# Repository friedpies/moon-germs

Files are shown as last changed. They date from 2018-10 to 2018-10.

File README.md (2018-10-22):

## Moon Germs
#### A hand-held, battery powered digital synthesizer based on the Teensy 3.2 and Audio Shield by www.pjrc.com
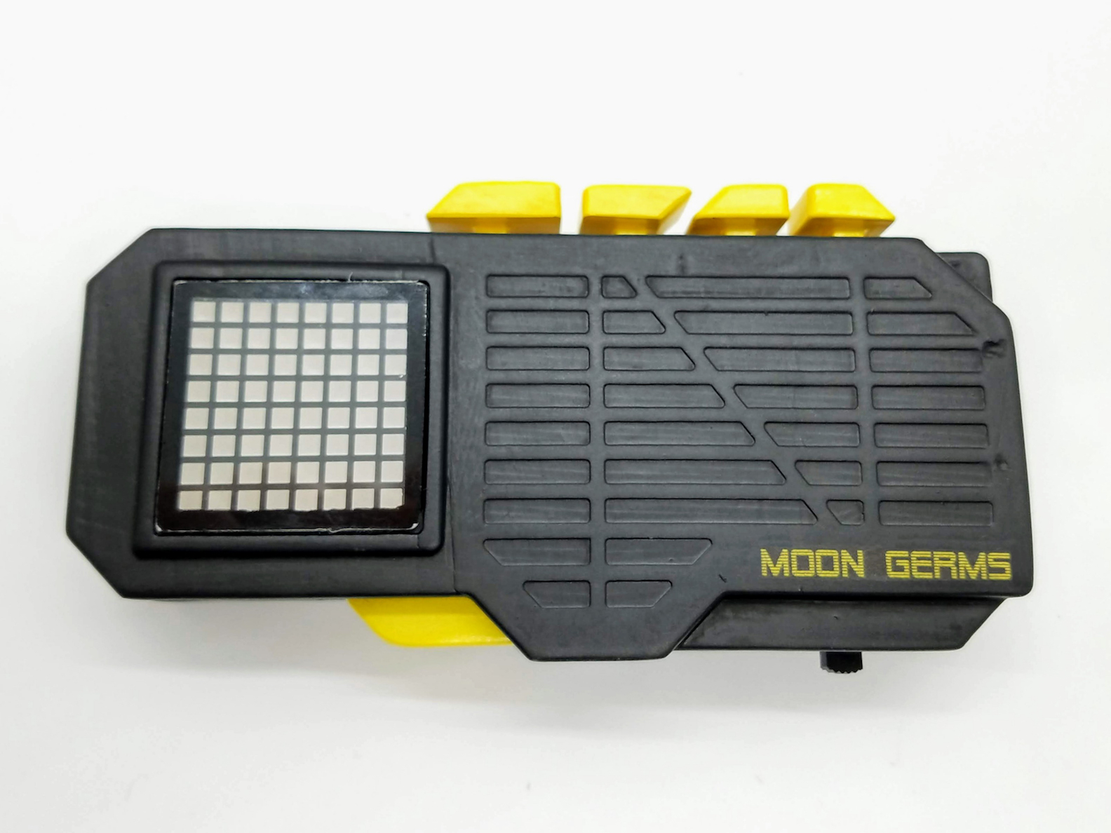
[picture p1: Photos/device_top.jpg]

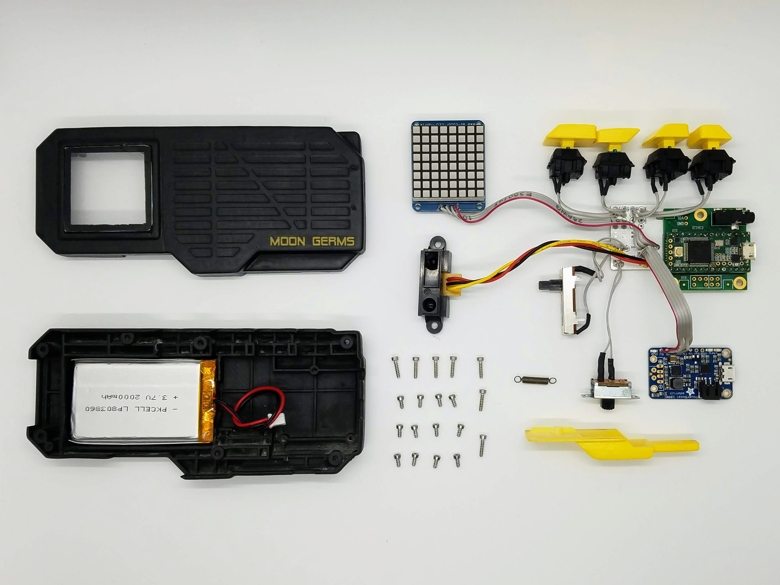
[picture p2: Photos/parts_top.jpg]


### Updates 10/21/18
*After making it into the semi-finals for the 2018 Hackaday challenge, I thought it would be fun to add some fun new features before submitting this project to the finals. In the past couple of days I've built a desktop app using Processing that connects to the device and allows you to update parameters in real time. I restructured the synth engine to include a LowPass filter and LFO. It was a pretty ambitious goal for me and I still have a lot of bugs to work out, but I have an MVP that works pretty well and looks pretty awesome too. See below for details about the app.*

### About the Device
A fun, pocket-sized synthesizer that uses an IR proximity sensor to modulate frequency. Using a combination of buttons and triggers, the device can produce several different waveforms and effects. An 8x8 LED matrix shows useful and colorful information while in use. Currently finishing up Rev 1.0

I wanted to explore digital synthesis using the Teensy Audio shield and experiment with a unique way of interacting with a synthesizer with minimal buttons/knobs, all while designing a device with an interesting and cyberpunk-y form factor. Although I'm a lifelong musician, I never really explored synthesis before and thought this would be a great way to dive in. This has been an awesome learning experience and has gotten me hooked! I'm excited to keep this up.

Traditional synthesizers can be intimidating to approach with all of their knobs, sliders and weird nomenclature, and difficult for a beginner to understand. This project aims to provide a fun and addicting way to mess around with a couple different waveforms and  explore creative and strange musical ideas. With only 4 buttons, and 2 analog inputs, interacting with the Moon Germs synthesizer and creating sound is really simple. Simply press down the "play" button and move your hand around relative to the IR sensor. Cycle through various waveforms with button 2, and switch octaves with buttons 3 & 4. For a "fatter" sound, apply force to the trigger to detune oscillator 2. The 8x8 display shows what type of waveform you're hearing, and dynamically speeds up or slows down with pitch.

When you're ready to take a deeper dive into the behind-the-scenes of synthesis, connect the device to the desktop app to adjust and tweak various parameters in a non-intimidating environment. Once connected, the app auto-loads the device's stored parameters according to their bank number. In addition to waveform selection, the adjustable parameters include oscillator volumes, detune amount, filter On/Off, cutoff, resonance, LFO on/off, rate, and amount. Additionally there is a trigger assignment option which allows the trigger to dynamic adjust parameters in real-time outside of the app. Currently, parameter adjustments will be saved on the device after disconnect, but will reset after a power cycle.

The entire design was made using open/free software and can be rebuilt with accessible tools and open electronics modules (see BOM).

--------
### Usage
The Moon Germs' synthesis engine is shown in the photo below. Pressing down button 1 activates the oscillators while their frequency is determined by the IR sensor. Button 2 cycles through 4 waveforms (saw, square, reverse saw, and triangle). Buttons 3 & 4 shift octaves up & down respectively. The spring loaded trigger applies a detune to oscillator 2. In standalone mode (not connected to the app), the filter and LFO are turned OFF for simplicity.
Device Demo
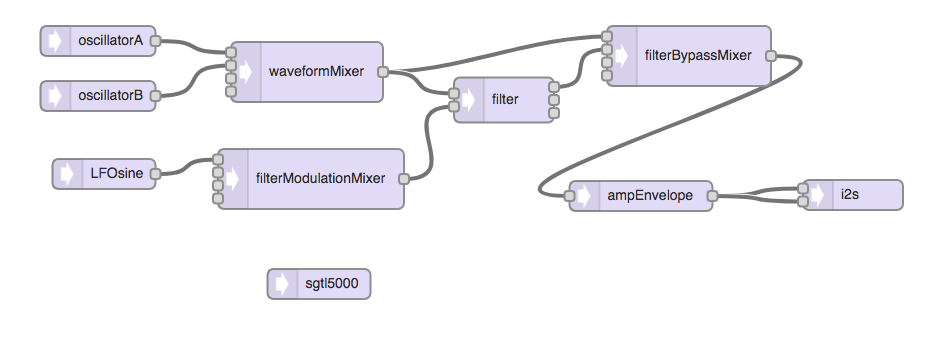
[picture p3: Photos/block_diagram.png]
Synth


### Desktop App
 Connecting the device to the desktop app allows the user to adjust various parameters to explore sound design. Once connected, the app auto-loads the device's stored parameters according to their bank number. In addition to waveform selection, the adjustable parameters include oscillator volumes, detune amount, filter On/Off, cutoff, resonance, LFO on/off, rate, and amount. Additionally there is a trigger assignment option which allows the trigger to dynamic adjust parameters in real-time outside of the app. Currently, parameter adjustments will be saved on the device after disconnect, but will reset after a power cycle.

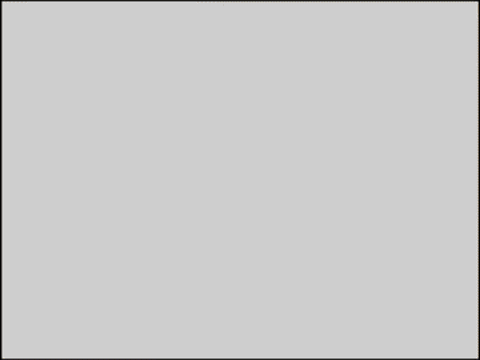
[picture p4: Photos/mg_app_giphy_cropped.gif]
App Demo


Desktop App Detail Information can be found [here](https://github.com/friedpies/moon-germs/tree/master/Desktop%20App)

--------
### Video Demos
[Submission Video](https://youtu.be/npFgwcqw3Ks)

[Demo 1](https://youtu.be/qyO1_fC_Kus)

[Demo 2](https://youtu.be/aUcpQy3lOxo)

--------
### BOM and Build Instructions
Full BOM and assembly instructions found [here](https://github.com/friedpies/moon-germs/blob/master/BUILD_INSTRUCTIONS.md)

--------
###  Electronics
- Schematic, Board, and CAM can be found [here](https://github.com/friedpies/moon-germs/tree/master/Eagle)
- PCB was manufactured using https://www.seeedstudio.com/fusion.html
--------
### Code
Arduino Code can be found [here](https://github.com/friedpies/moon-germs/tree/master/Arduino/moonGerms)

--------
### CAD + 3D Printing
STEP files of full assembly and STL files for 3D printing can be found [here](https://github.com/friedpies/moon-germs/tree/master/CAD)

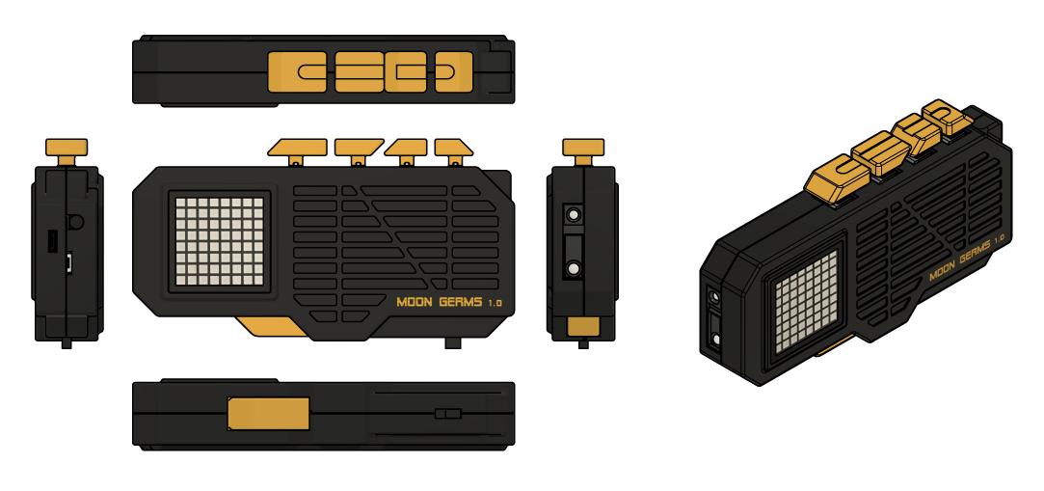
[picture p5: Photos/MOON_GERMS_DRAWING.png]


--------
### Acknowledgments
- [PJRC](www.pjrc.com) for developing such a great audio shield and great tutorials, this thing is awesome!
- [Notes and Volts](www.notesandvolts.com) for such useful tutorials on how to use the Teensy Audio shield
- [LED Matrix Editor](https://xantorohara.github.io/led-matrix-editor/) A great GUI for creating 8x8 matrix animations.
- [Adafruit](www.adafruit.com) for their great electronics modules and Arduino libraries.
- Several [GrabCAD](www.grabcad.com) users for uploading and sharing their component models (shoutouts in /CAD folder)
- Shoutout to my cousin, Justin Marut, for translating "Moon Germs" into Japanese for me
thanksjustin
--------
### Author & License
Author: Kenneth Marut (www.kennethmarut.com)

License: MIT

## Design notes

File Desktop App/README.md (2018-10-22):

### Desktop App (alpha version)

#### About
- App was built by Kenneth Marut using [Processing 3](https://processing.org/). If you're interested in messing around with the code, Processing can be downloaded [here](https://processing.org/download/). Once downloaded, open "moon_germs_app.pde"
- This is still very much an alpha version. The basic functionality of the program works, but there are several bugs. Additionally, the "save" feature has not been implemented.
- For Mac .app file click [here](https://github.com/friedpies/moon-germs/tree/master/Desktop%20App/moon_germs_app/application.macosx), and .exe files for both Mac and Windows [32](https://github.com/friedpies/moon-germs/tree/master/Desktop%20App/moon_germs_app/application.windows32) & [64](https://github.com/friedpies/moon-germs/tree/master/Desktop%20App/moon_germs_app/application.windows64) bit

#### Usage
- Launch app on either windows or mac using the methods listed above
- Turn on Moon Germs device and wait until boot up screen is finished
- Connect device to computer using micro-USB cable
- Click "SELECT COM PORT" dropdown menu and select your device's port. The device will display an animation upon connecting

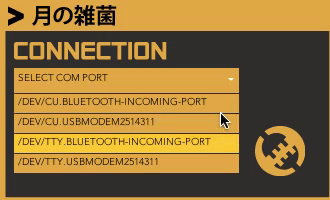
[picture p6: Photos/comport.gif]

- Data from the device will auto-load into the app
- Experiment with the sounds by adjusting the knobs and switches, pressing down the device buttons and using the trigger will allow you to hear your creation!
- Cycle through banks with button 2


- To disconnect, press the disconnect icon. Unplug the usb cable, your changes will be saved until the device is power cycled (this will be updated in a later revision)

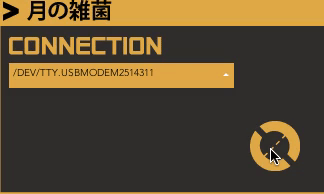
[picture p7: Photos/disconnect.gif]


#### About the Synth Structure and Adjustable Parameters
- A block diagram of the signal flow can be seen here


- When the filter is turned "ON", the filterBypassMixer turns off channel 1, and turns on channel 2
- In order to hear the effects of the LFO, the filter must also be turned on
- The "Trigger Func" parameter causes the trigger to attenuate the selected parameter(s): Oscillator 2 Detune, Filter Cutoff Frequency, LFO Rate, and LFO Amount.

#### Acknowledgments
- http://www.sojamo.de/libraries/controlP5 for writing a great GUI library, ControlP5

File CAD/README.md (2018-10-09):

- Full CAD assembly can be found in /STEPs
- Files used for 3D printing can be found in /STLs. Parts are designed for resin printing, but should also print fine with FDM printers


### Acknowledgments
I used a couple of pre-designed CAD models from [GrabCAD](www.grabcad.com), including:
- Rafael's [model](https://grabcad.com/library/adafruit-powerboost-1000c-3) of the Adafruit Powerboost 1000C 
- Kevin Yu's [model](https://grabcad.com/library/cherry-mx-switches-mx-1) of the Cherry MX switch
- Aron Rubin's [model](https://grabcad.com/library/teensy-3-2-2) of the Teensy 3.2
- Emad's [model](https://grabcad.com/library/sharp-gp2y0a21yk0f) of the Sharp IR sensor

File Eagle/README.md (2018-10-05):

ECAD files were designed and generated using Autodesk Eagle and manufactured using [Seeed Studio Fusion](www.seeedstudio.com)

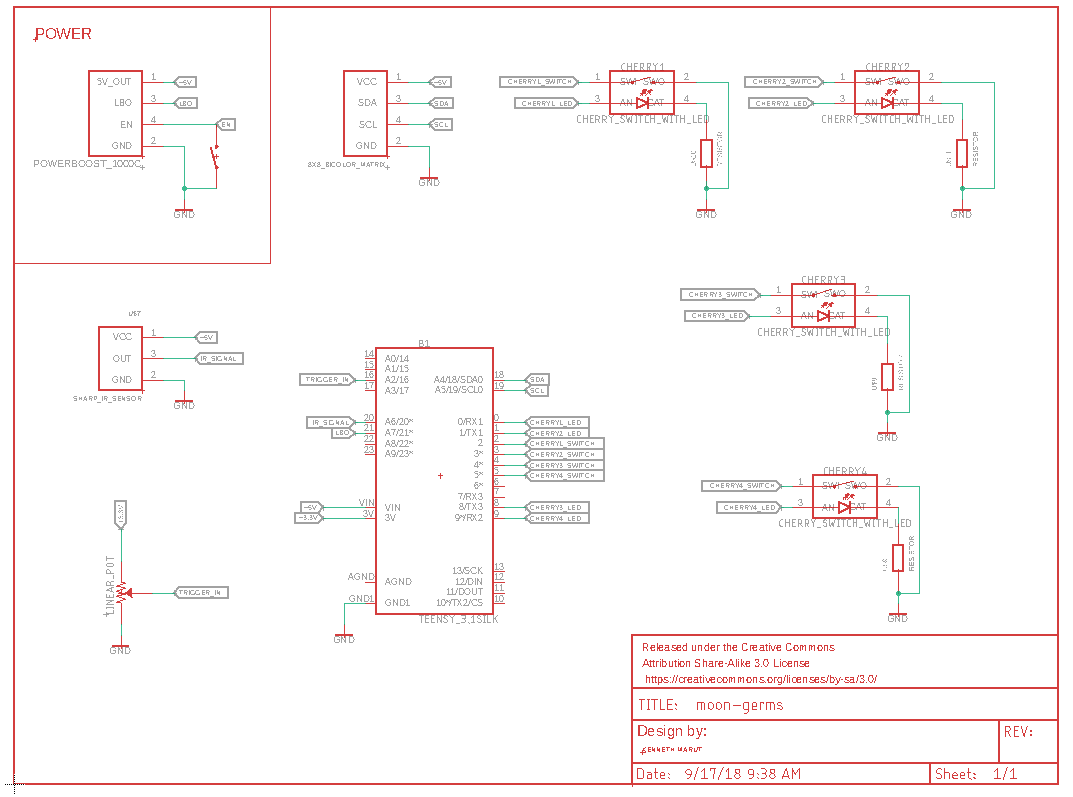
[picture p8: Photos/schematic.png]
Schematic

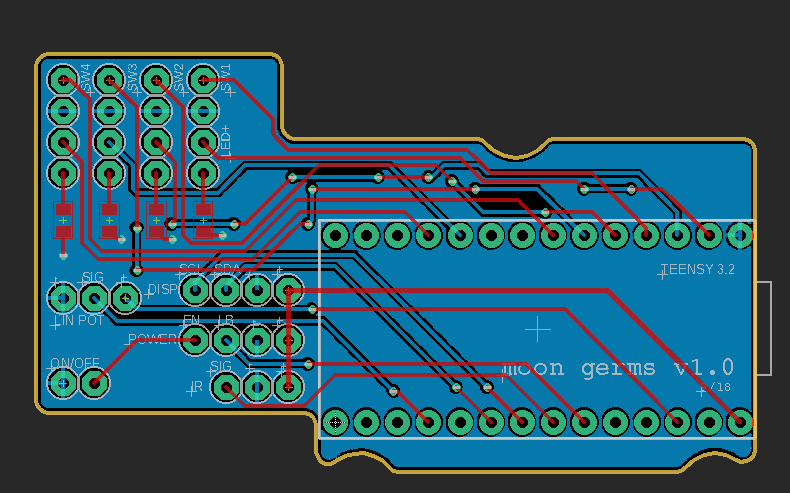
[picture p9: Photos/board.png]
Board


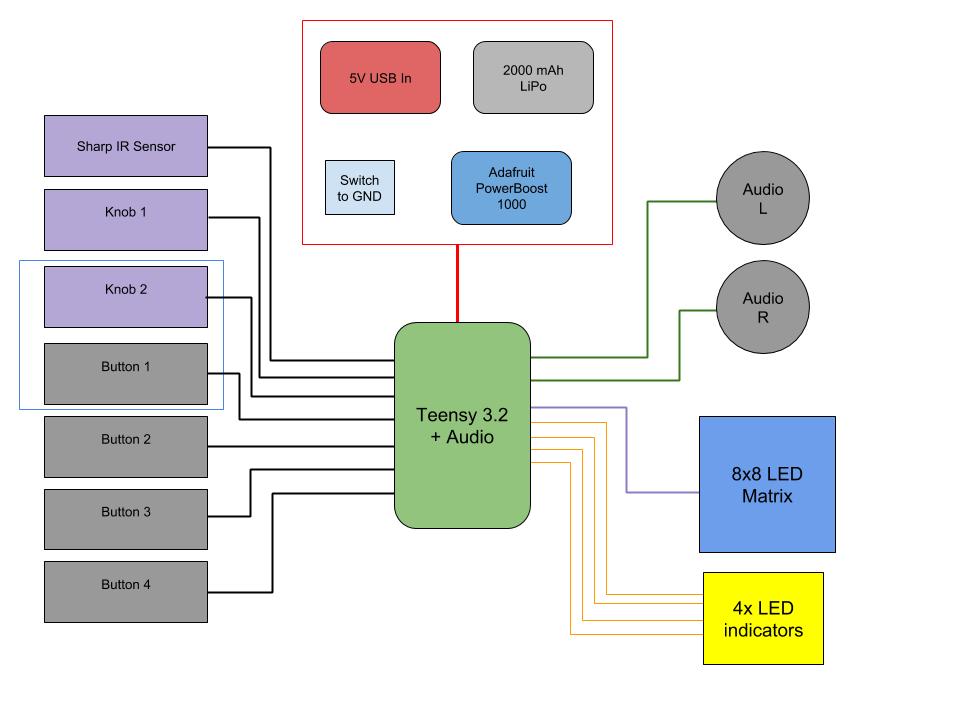
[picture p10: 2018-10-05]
Photos/Moon Germs Electronics Architecture.jpg

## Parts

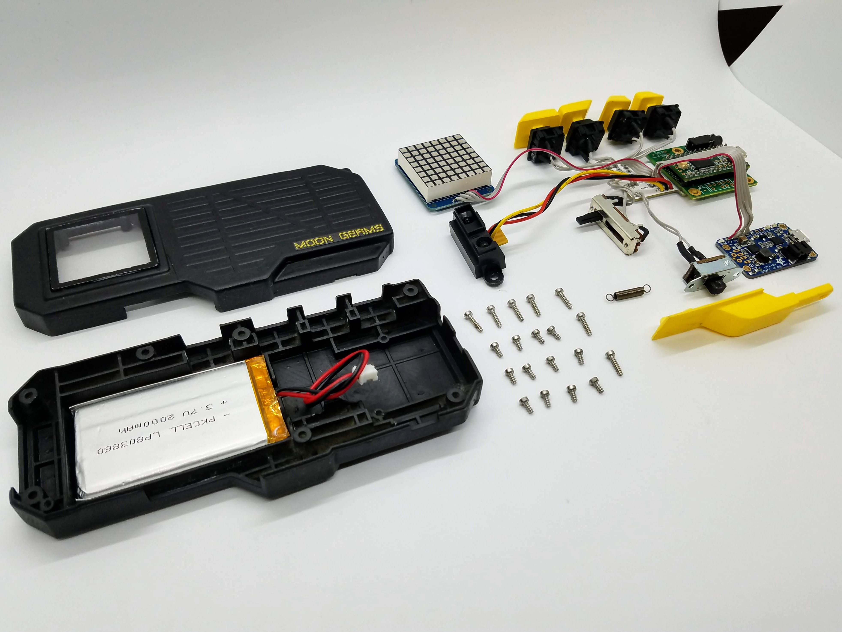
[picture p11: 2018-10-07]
Photos/parts_angled.jpg

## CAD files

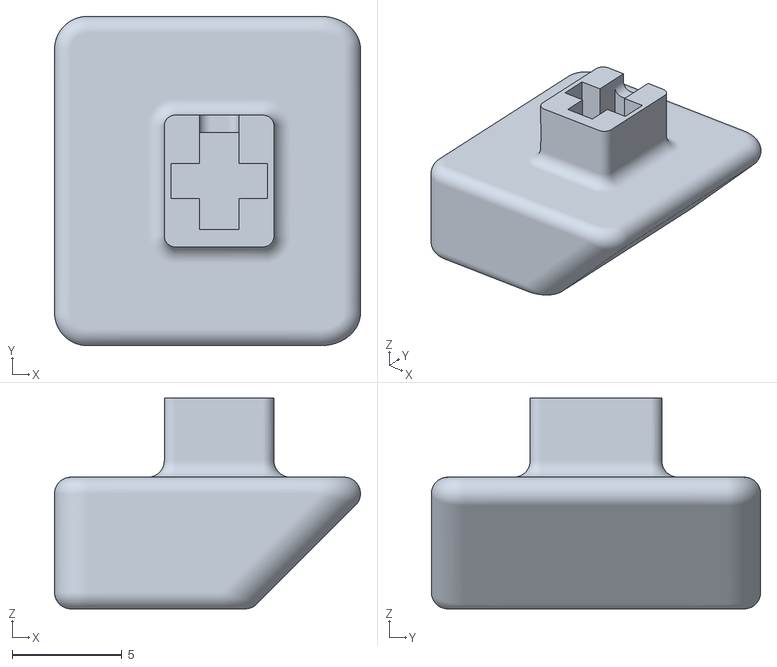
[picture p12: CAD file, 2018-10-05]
CAD/STLs/MOON_GERMS_KEY_4.stl
13.9 x 15.0 x 9.60

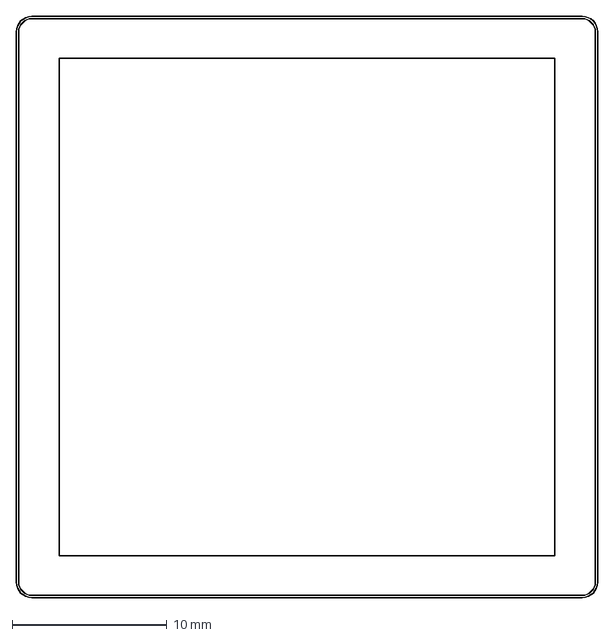
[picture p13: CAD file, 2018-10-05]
CAD/STLs/MOON_GERMS_DISPLAY_SHIELD.dxf
37.6 x 37.6 mm

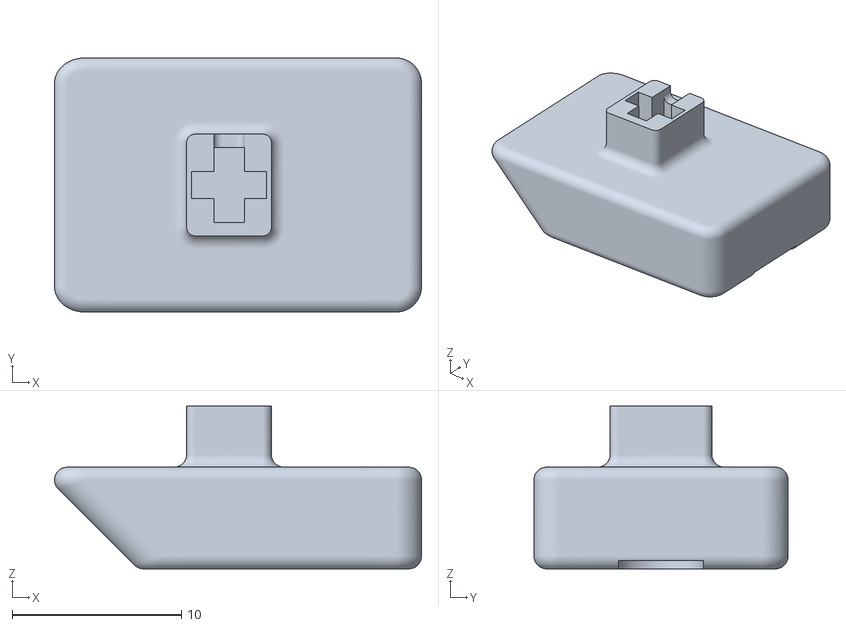
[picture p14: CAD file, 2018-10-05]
CAD/STLs/MOON_GERMS_KEY_1.stl
21.7 x 15.0 x 9.60

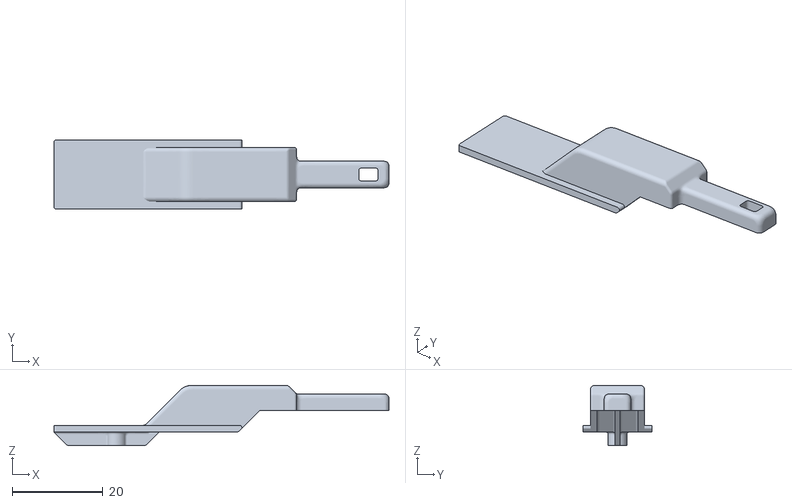
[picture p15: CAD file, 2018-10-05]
CAD/STLs/MOON_GERMS_TRIGGER.stl
73.8 x 15.2 x 13.3

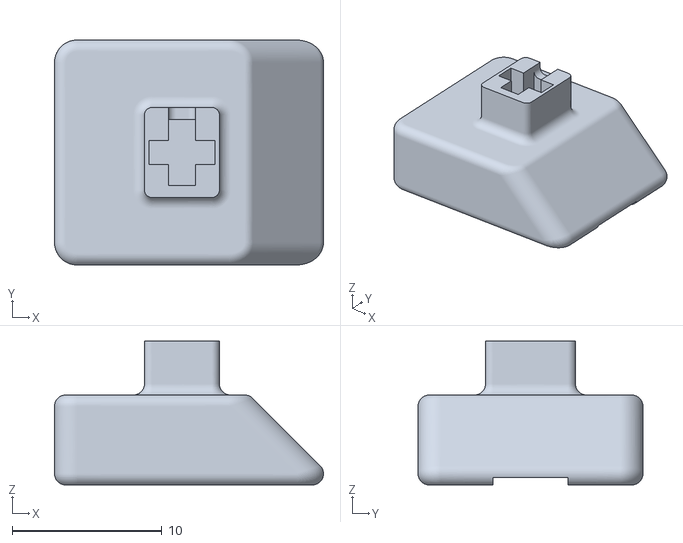
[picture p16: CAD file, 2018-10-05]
CAD/STLs/MOON_GERMS_KEY_2.stl
17.9 x 15.0 x 9.60

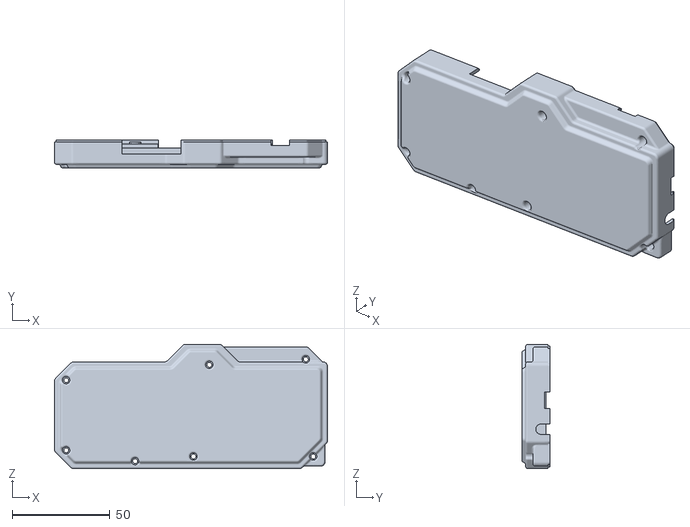
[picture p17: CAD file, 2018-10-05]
CAD/STLs/MOON_GERMS_ENCLOSURE_BOTTOM.stl
139.7 x 14.3 x 63.6

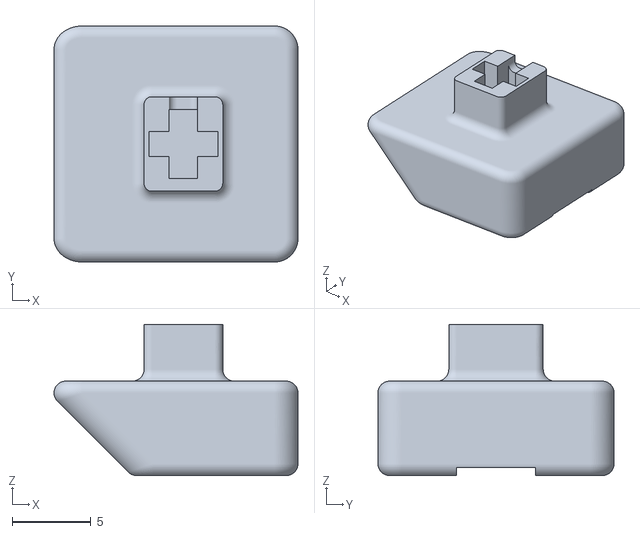
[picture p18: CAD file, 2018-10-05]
CAD/STLs/MOON_GERMS_KEY_3.stl
15.5 x 15.0 x 9.60

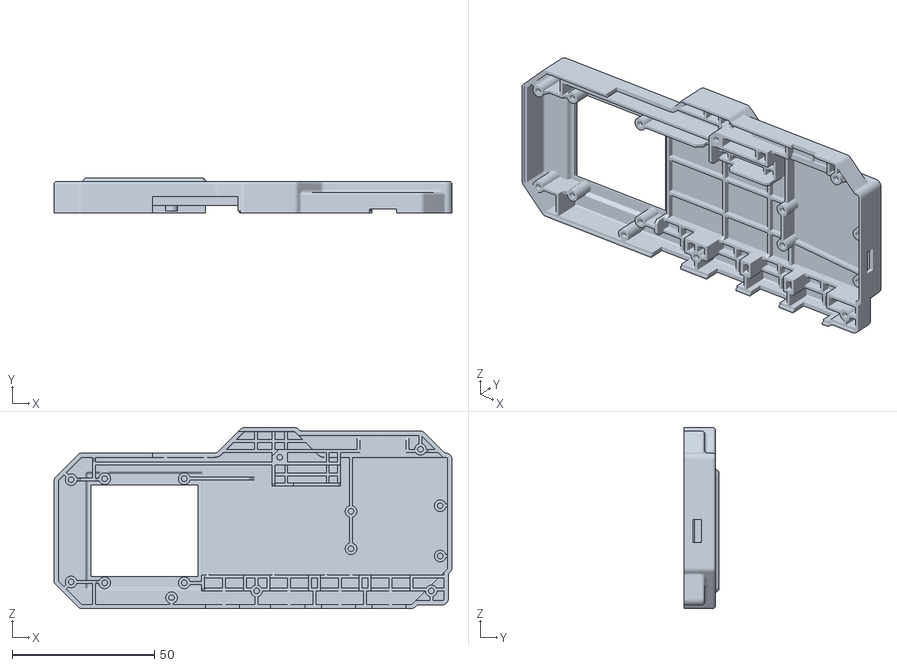
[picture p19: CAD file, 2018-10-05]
CAD/STLs/MOON_GERMS_ENCLOSURE_TOP.stl
139.7 x 12.4 x 63.6

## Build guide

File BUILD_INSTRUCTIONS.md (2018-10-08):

### Moon Germs Pocket Synthesizer Build Instructions

#### Bill of Materials

***Off the Shelf Electronics:***
- 1x [Teensy 3.2 Development Board, no headers](https://www.pjrc.com/store/teensy32.html) $19.80
- 1x [Teensy Audio Adapter](https://www.pjrc.com/store/teensy3_audio.html) $14.25
- 1x [Adafruit PowerBoost 1000](https://www.adafruit.com/product/2465) $19.95
- 1x [Adafruit Bicolor LED Square Matrix with I2C Backpack](https://www.adafruit.com/product/902) $15.95
- 1x [2000 mAh rechargable LiPo Battery](https://www.digikey.com/product-detail/en/adafruit-industries-llc/2011/1528-1857-ND/6612469) $12.50
- 4x [Cherry Switches](https://www.sparkfun.com/products/13834) $3.80
- 1x [Sharp IR Sensor GP2Y0A41SK0F](https://www.sparkfun.com/products/12728) $13.95
- 1x [Bourns Linear Potentiometer PTA1543-2010CIB103](https://www.digikey.com/product-detail/en/bourns-inc/PTA1543-2010CIB103/PTA1543-2010CIB103-ND/3781161) $1.29
- 1x [SPST Toggle Switch](https://www.digikey.com/product-detail/en/cw-industries/GF-123-3011/CWI334-ND/4089772) $0.73

***Custom Electronics:***
- 1x [Moon Germs Teensy 3.2 Custom Breakout Board](https://github.com/friedpies/moon-germs/tree/master/Eagle)

***Off the Shelf Hardware:***
- 1x [Spring](https://www.mcmaster.com/9654k951) $7.00
- 12x [4mm M2 Plastic Screws](https://www.mcmaster.com/96817a840) $7.50
- 7x [8mm M2 Plastic Screws](https://www.mcmaster.com/96817a846) $8.12

***3D Printed / Laser Cut Parts:***
- [Enclosure, Bottom](https://github.com/friedpies/moon-germs/blob/master/CAD/STLs/MOON_GERMS_ENCLOSURE_BOTTOM.stl)
- [Enclosure, Top](https://github.com/friedpies/moon-germs/blob/master/CAD/STLs/MOON_GERMS_ENCLOSURE_TOP.stl)
- [Trigger](https://github.com/friedpies/moon-germs/blob/master/CAD/STLs/MOON_GERMS_TRIGGER.stl)
- [Key Cap 1](https://github.com/friedpies/moon-germs/blob/master/CAD/STLs/MOON_GERMS_KEY_1.stl)
- [Key Cap 2](https://github.com/friedpies/moon-germs/blob/master/CAD/STLs/MOON_GERMS_KEY_2.stl)
- [Key Cap 3](https://github.com/friedpies/moon-germs/blob/master/CAD/STLs/MOON_GERMS_KEY_3.stl)
- [Key Cap 4](https://github.com/friedpies/moon-germs/blob/master/CAD/STLs/MOON_GERMS_KEY_4.stl)
- [Acrylic Display Cover](https://github.com/friedpies/moon-germs/blob/master/CAD/STLs/MOON_GERMS_DISPLAY_SHIELD.dxf)

### Gather Parts:
- Obtain all off-the-shelf hardware listed above
- 3D print all plastic components, 0.1mm to 0.15mm resolution for FDM printers with a 30% infill should be fine,
 0.03mm - 0.05mm for resin printers
- Cut display cover using 0.06" clear acrylic with a laser or die-cutter (optional)
- [Breakout board](https://github.com/friedpies/moon-germs/tree/master/Eagle) can be manufactured with PCB manufacturer of your choice (I use seeedstudio)

### Assemble/Solder Electronics:
- Solder Teensy 3.2 and audio shield using headers with Teensy ON TOP of audio shield, then solder Teensy+Audio shield to breakout board, clip headers with flush cutters:
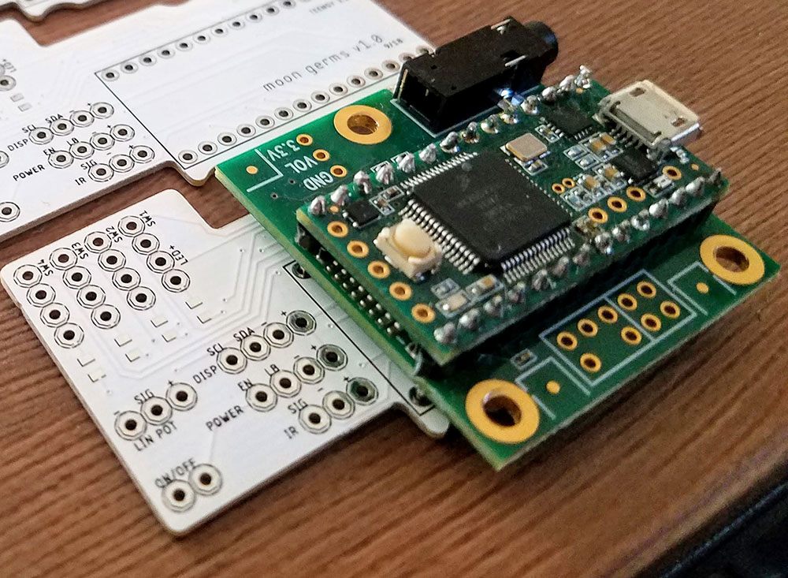
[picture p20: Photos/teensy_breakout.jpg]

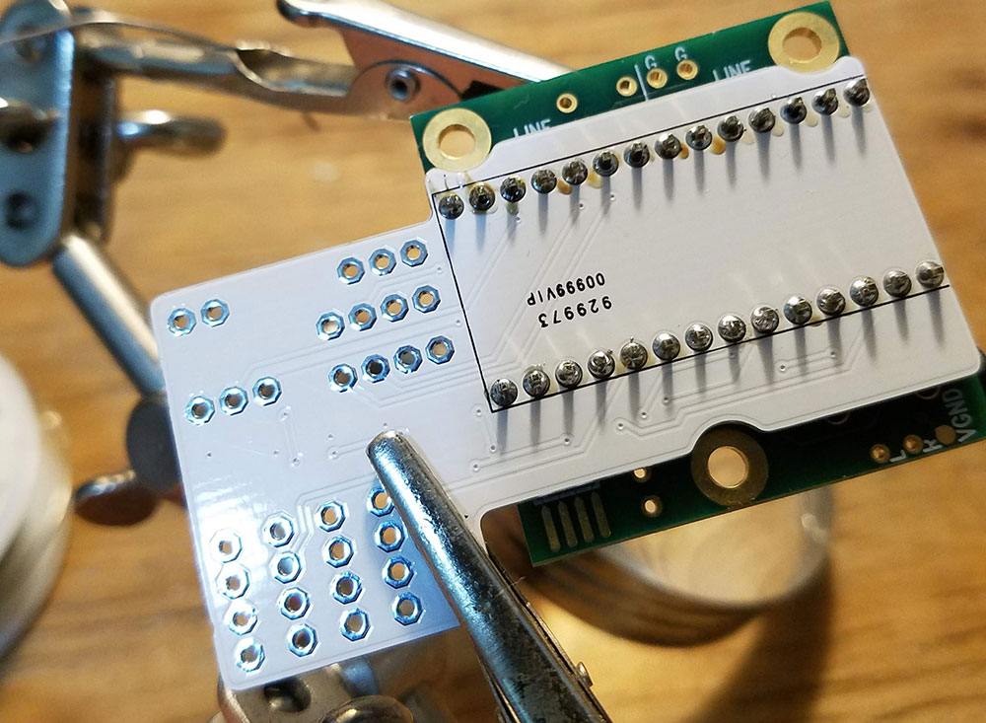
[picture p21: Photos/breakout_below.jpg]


- Assemble all electronics modules according to their documentation, DO NOT attach any headers. (Visit product links for assembly instructions)
- Solder all electronic components to breakout board according to the image below, refer to silkscreen for details:
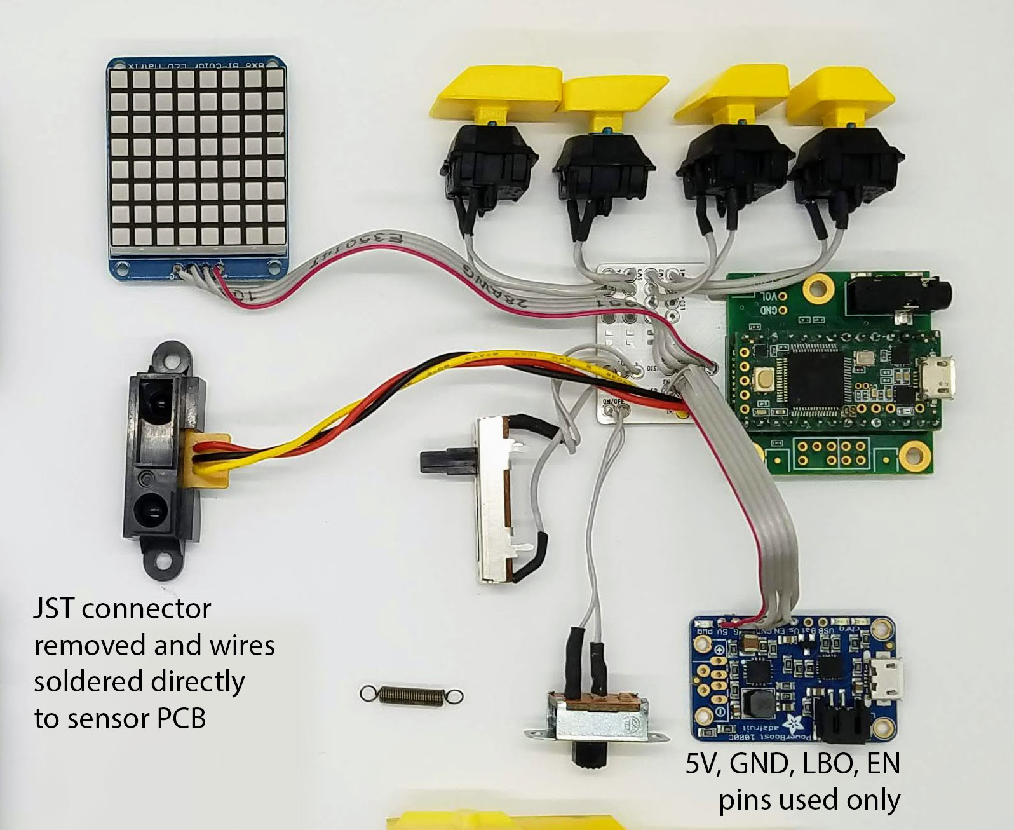
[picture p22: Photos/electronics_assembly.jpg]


### Upload Firmware to Teensy 3.2
- Install Arduino IDE from [www.arduino.cc](https://www.arduino.cc/)
- Install Teensy loader software from [https://www.pjrc.com/teensy/loader.html](https://www.pjrc.com/teensy/loader.html)
- Download and open [Moon Germs firmware](https://github.com/friedpies/moon-germs/tree/master/Arduino/moonGerms) with Arduino IDE
- Install necessary Arduino libraries listed at the top of the moonGerms.ino file
- Connect Teensy board to computer with a micro-USB cable and upload moonGerms.ino, the 8x8 display should flash with a bootup Animation if the upload was successful

### Enclosure Assembly
- Assemble lower-half of enclosure according to the image below, use hot-glue to hold linear potentiometer in place:
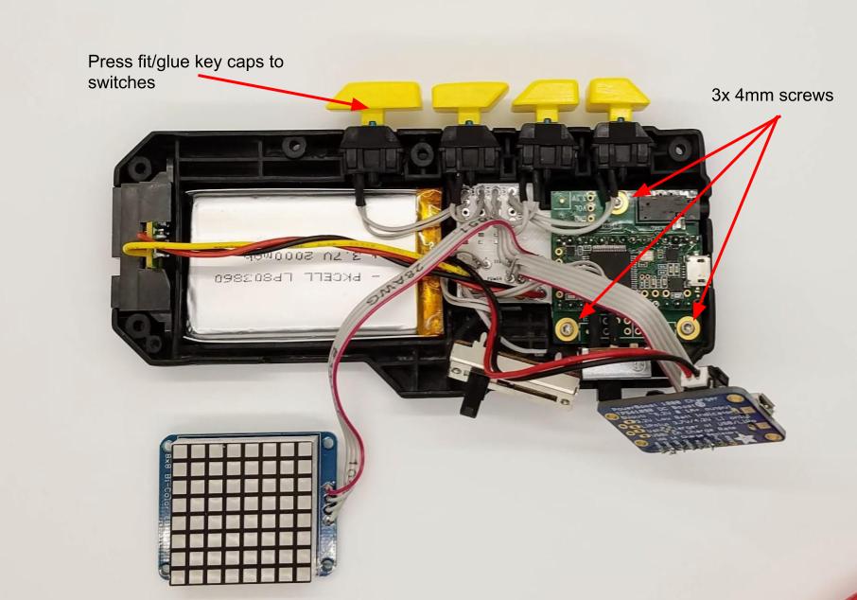
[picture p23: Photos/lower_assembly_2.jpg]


- Assemble spring-trigger and insert into lower-half of enclosure using 2x 4mm M2 screws, ensure that linear potentiometer is properly captured by trigger cutout:
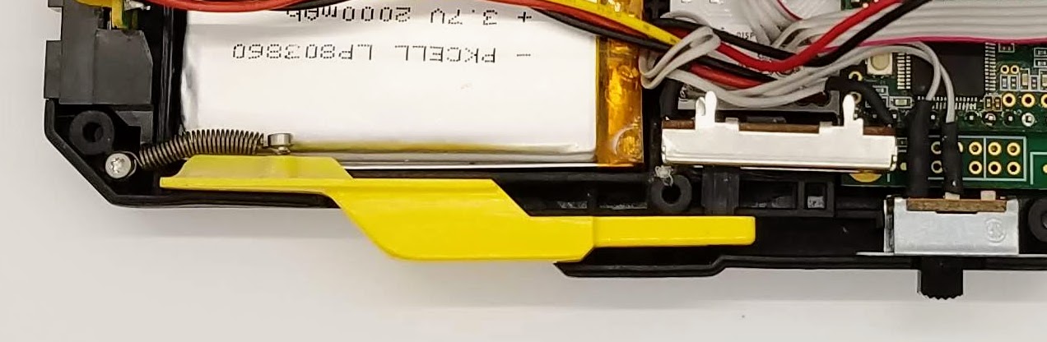
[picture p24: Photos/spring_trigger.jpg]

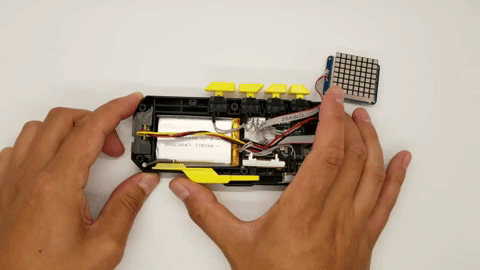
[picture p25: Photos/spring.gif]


- Assemble upper-half of enclosure according to the image below:
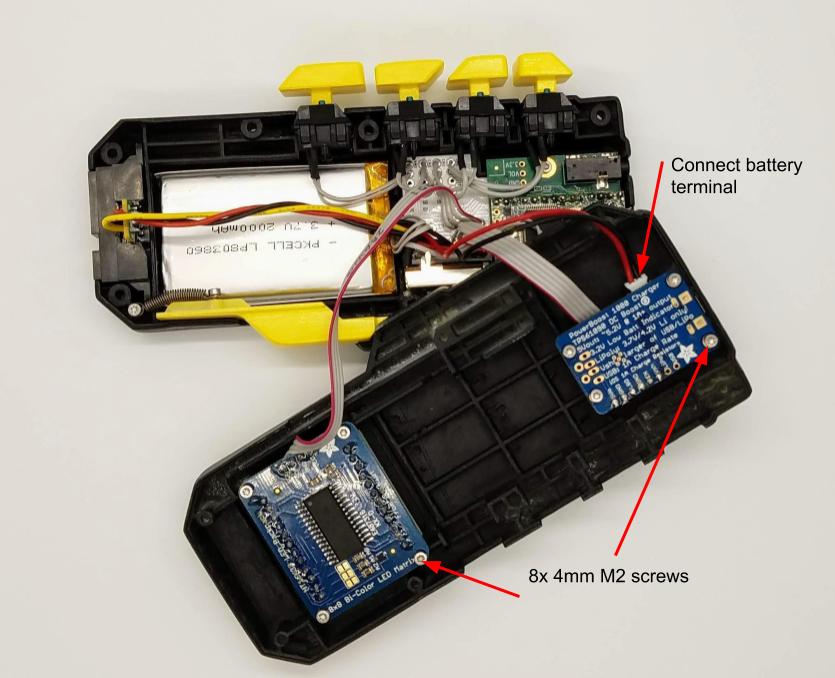
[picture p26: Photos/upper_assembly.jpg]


### Test device
- Power on the device by flipping the on-off switch located on the bottom right side of the device, the display should play a bootup animation and pressing down button 1 should display a waveform. Plug in a pair of headphones to ensure the device is generating sound and play with the IR and trigger. If there are any issues, check connections!

### Final assembly!
- Carefully assemble the two halves of the enclosure, ensuring that wires are not caught or snagged during assembly. Use 7x 8mm M2 plastic screws to hold enclosure together.


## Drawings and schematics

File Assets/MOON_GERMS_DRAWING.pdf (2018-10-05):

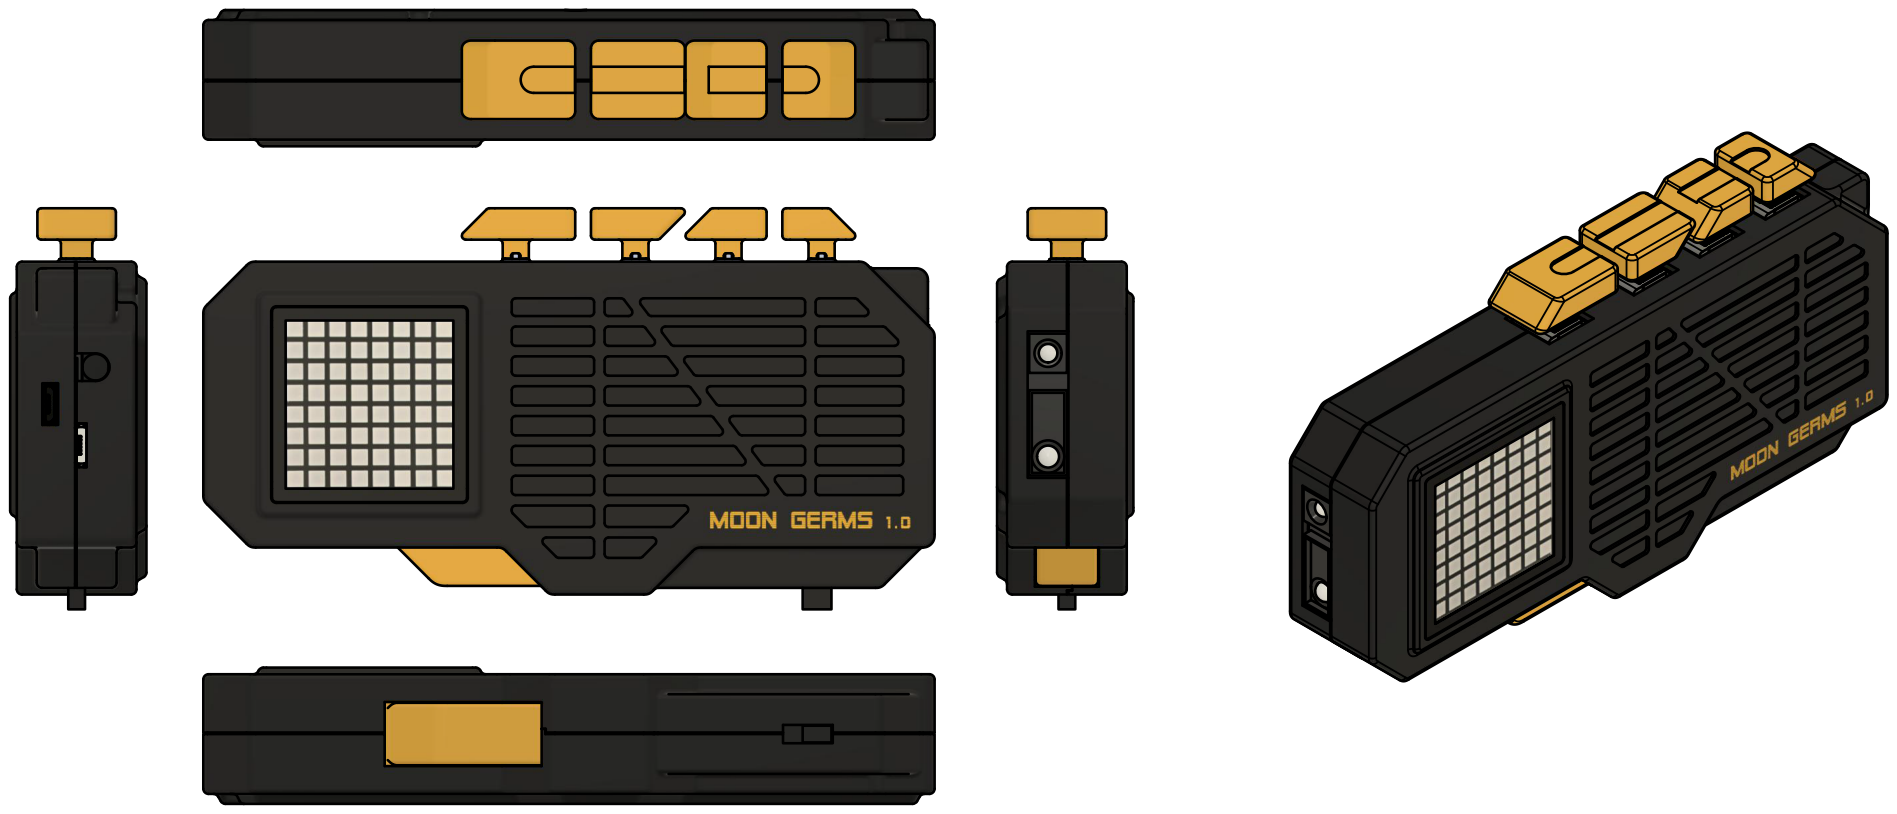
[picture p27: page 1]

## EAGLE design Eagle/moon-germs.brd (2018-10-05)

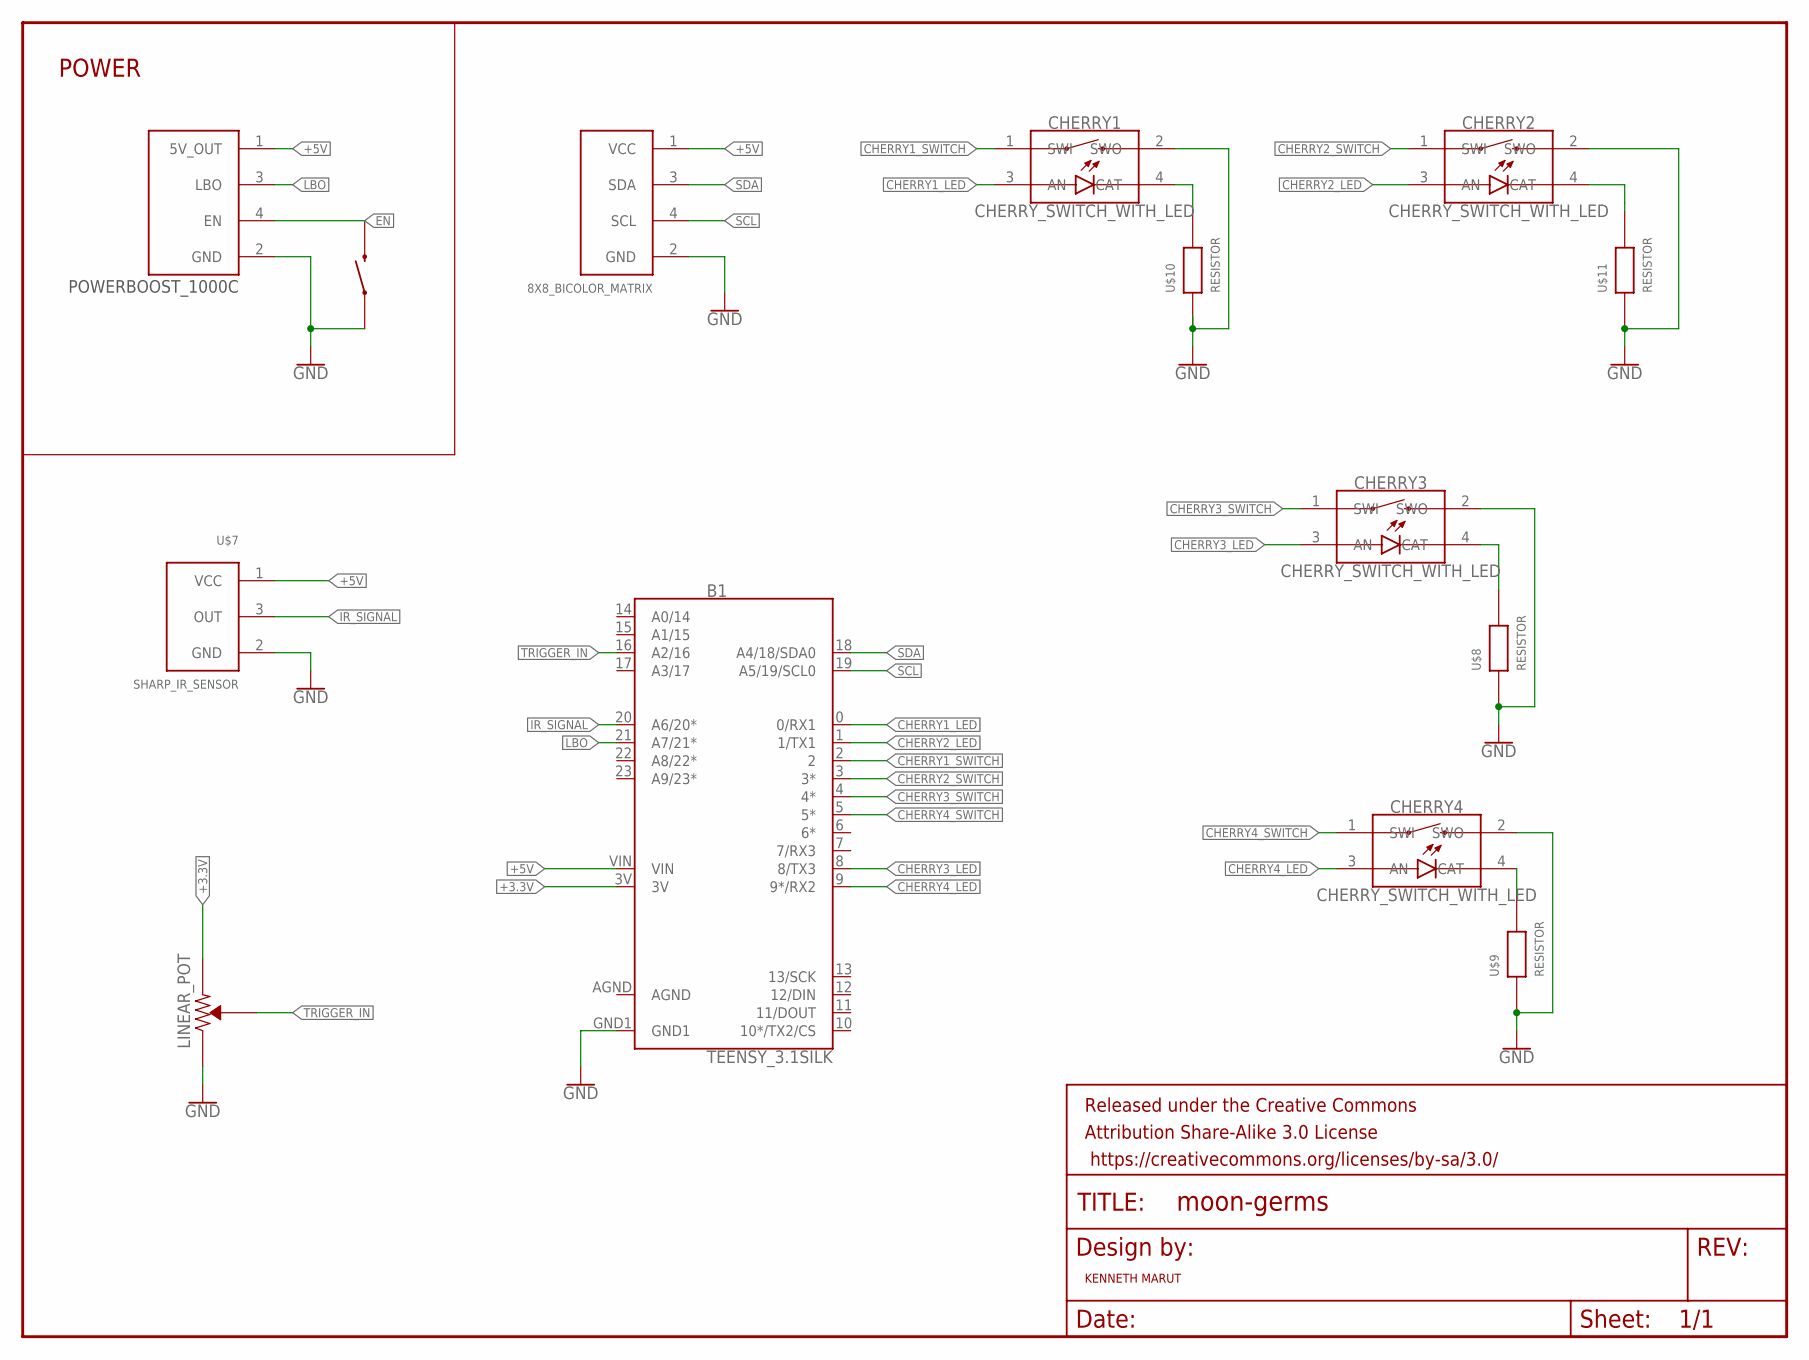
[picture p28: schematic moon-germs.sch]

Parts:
B1: TEENSY_3.1SILK; TEENSY_3.1
CHERRY1, CHERRY2, CHERRY3, CHERRY4: CHERRY_SWITCH_WITH_LED; 1X04
FRAME1: FRAME-LETTER; CREATIVE_COMMONS
U$1: 8X8_BICOLOR_MATRIX; 1X04
U$6: SPST-SWITCH; 1X02
U$7: SHARP_IR_SENSOR; 1X03
U$8, U$9, U$10, U$11: RESISTOR; 0805
U$12: POWERBOOST_1000C; 1X04
U$13: LINEAR_POT; 1X03

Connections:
+3.3V: B1.3V, U$13.1 (+)
+5V: B1.VIN, U$1.1 (VCC), U$7.1 (VCC), U$12.1 (5V_OUT)
AGND: B1.AGND
CHERRY1_LED: B1.0 (0/RX1), CHERRY1.3 (AN)
CHERRY1_SWITCH: B1.2, CHERRY1.1 (SWI)
CHERRY2_LED: B1.1 (1/TX1), CHERRY2.3 (AN)
CHERRY2_SWITCH: B1.3 (3*), CHERRY2.1 (SWI)
CHERRY3_LED: B1.8 (8/TX3), CHERRY3.3 (AN)
CHERRY3_SWITCH: B1.4 (4*), CHERRY3.1 (SWI)
CHERRY4_LED: B1.9 (9*/RX2), CHERRY4.3 (AN)
CHERRY4_SWITCH: B1.5 (5*), CHERRY4.1 (SWI)
EN: U$6.2 (SWO), U$12.4 (EN)
GND: B1.GND1, CHERRY1.2 (SWO), CHERRY2.2 (SWO), CHERRY3.2 (SWO), CHERRY4.2 (SWO), U$1.2 (GND), U$6.1 (SWI), U$7.2 (GND), U$8.1, U$9.1, U$10.1, U$11.1, U$12.2 (GND), U$13.3 (-)
IR_SIGNAL: B1.20 (A6/20*), U$7.3 (OUT)
LBO: B1.21 (A7/21*), U$12.3 (LBO)
unnamed: CHERRY1.4 (CAT), U$10.2
unnamed: CHERRY4.4 (CAT), U$9.2
unnamed: CHERRY3.4 (CAT), U$8.2
unnamed: CHERRY2.4 (CAT), U$11.2
SCL: B1.19 (A5/19/SCL0), U$1.4 (SCL)
SDA: B1.18 (A4/18/SDA0), U$1.3 (SDA)
TRIGGER_IN: B1.16 (A2/16), U$13.2 (W)

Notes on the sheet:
KENNETH MARUT
POWER

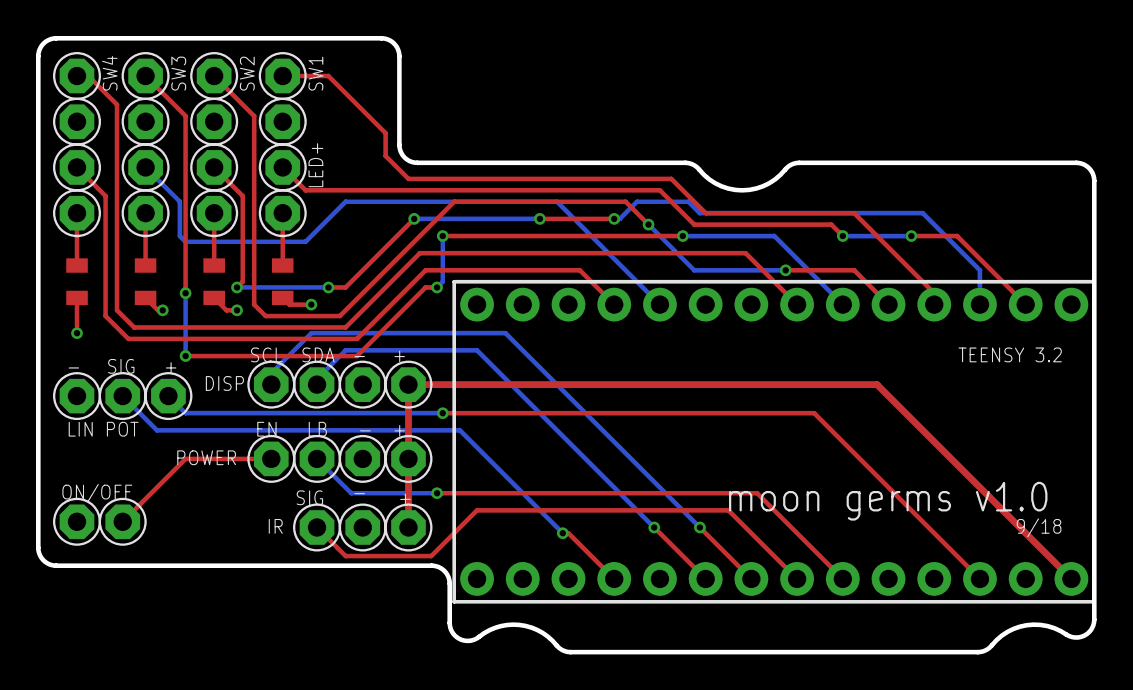
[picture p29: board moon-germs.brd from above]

Board: 2 copper layers, 58.7 x 34.1 mm, 15 parts (0 on the bottom side), 21 nets.

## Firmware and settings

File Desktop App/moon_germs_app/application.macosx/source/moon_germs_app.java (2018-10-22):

import processing.core.*; 
import processing.data.*; 
import processing.event.*; 
import processing.opengl.*; 

import controlP5.*; 
import processing.serial.*; 

import java.util.HashMap; 
import java.util.ArrayList; 
import java.io.File; 
import java.io.BufferedReader; 
import java.io.PrintWriter; 
import java.io.InputStream; 
import java.io.OutputStream; 
import java.io.IOException; 

public class moon_germs_app extends PApplet {

// Moon Germs Desktop App
// V0.1 Processing Code

// Hardware and software files can be found at: https://github.com/friedpies/moon-germs
// Project Details: https://hackaday.io/project/161208-moon-germs
// License: MIT




PImage splashScreen;
PImage appBackground;
PImage[] buttonOnImages = new PImage[4];
PImage[] buttonOffImages = new PImage[4];
PImage triggerImage; 
PImage drawingOverlayImage;
PFont sevenSegment;
boolean runOnce = true; // boolean to run splash screen once

ControlP5 cp5;
Button closeButton;

ScrollableList comPortList;
Toggle connectionToggle;

RadioButton oscAWaveformRadioButton;
Knob oscAVolumeKnob;

RadioButton oscBWaveformRadioButton;
Knob oscBVolumeKnob;
Knob oscBDetuneKnob;

Knob lfoRateKnob;
Knob lfoAmountKnob;
Toggle lfoOnOffToggle;
RadioButton lfoDestRadioButton;

Toggle filterOnOffToggle;
Knob filterCutoffKnob;
Knob filterQKnob;

Knob ampAttackKnob;
Knob ampReleaseKnob;
Knob masterVolumeKnob;

CheckBox triggerDestCheckBox;

Button loadButton;
Button saveButton;

CheckBox displayCheckBox;


Serial mgPort;

String portName;
String incomingData = "";
boolean isDeviceConnected = false;

// Colors
int darkYellow = color(230, 169, 64);
int lightYellow = color(255, 200, 50);
int black = color(0);

boolean keyBounce = true;

//SYNCED VARIABLES WITH DEVICE
String loadData = ""; // String to hold all incoming data
int bankIndex = 0;
final int numberOfBanks = 4;

float[] MasterVolume = new float[numberOfBanks];

int[] OscAWaveform = new int[numberOfBanks];
float[] OscAVolume = new float[numberOfBanks];

int[] OscBWaveform = new int[numberOfBanks];
float[] OscBVolume = new float[numberOfBanks];
float[] OscBDetune = new float[numberOfBanks];

float[] NoiseVolume = new float[numberOfBanks];

int[] LFOOnOff = new int[numberOfBanks];
float[] LFORate = new float[numberOfBanks];
float[] LFOAmount = new float[numberOfBanks];
int[] LFODest = new int[numberOfBanks];

int[] FilterOnOff = new int[numberOfBanks];
float[] FilterQ = new float[numberOfBanks];
float[] FilterCutoff = new float[numberOfBanks];

int[][] TriggerDest = new int[numberOfBanks][4];

int[] AmpAttack = new int[numberOfBanks];
int[] AmpRelease = new int[numberOfBanks];



float[] defaultOscAWaveform = {0, 0, 1, 0, 0};
float[] defaultOscBWaveform = {1, 0, 0, 0, 0};


boolean[] buttonDisplays = {false, false, false, false};

//PImage[] buttonOffImages = {loadImage("button1-off.png"), loadImage("button2-off.png"), loadImage("button3-off.png"), loadImage("button4-off.png")};
int[][] buttonCoordinates = {
  {579, 151}, 
  {679, 151}, 
  {757, 152}, 
  {828, 152}};

int triggerDelta;
String appState = "SPLASH";

public void settings() {
  size(1000, 750);
}

public void setup() {
  noStroke();
  
  splashScreen = loadImage("moon-germs-splash3d.png");
  buttonOnImages[0] = loadImage("button1-on.png");
  buttonOnImages[1] = loadImage("button2-on.png");  
  buttonOnImages[2] = loadImage("button3-on.png");  
  buttonOnImages[3] = loadImage("button4-on.png");

  buttonOffImages[0] = loadImage("button1-off.png");
  buttonOffImages[1] = loadImage("button2-off.png");  
  buttonOffImages[2] = loadImage("button3-off.png");  
  buttonOffImages[3] = loadImage("button4-off.png");
  triggerImage = loadImage("trigger.png");
  drawingOverlayImage = loadImage("drawing-overlay.png");
  sevenSegment = loadFont("SevenSegmentRegular-53.vlw");
  textFont(sevenSegment);
  textAlign(CENTER, CENTER);
  frameRate(60); // 60 fps
  cp5 = new ControlP5(this);
}

public void draw() {

  switch (appState) {
  case "SPLASH": // splash screen on start up
    splashSequence(0.5f, 1, 1.5f); // need to fix bug, not quite right
    if (frameCount > (30 * 2)) {
      appState = "NORMAL"; // switch states and setup GUI before moving to normal operation
      setupGui();
      appBackground = loadImage("app-design.png");
    }
    break;

  case "NORMAL":
    image(appBackground, 0, 0);
    image(triggerImage, 532 + triggerDelta, 419);
    image(drawingOverlayImage, 0, 0);
    fill(255, 0, 0);
    text(bankIndex, 430, 80);
    showButtons(buttonDisplays);
    fill(darkYellow);

    //if (incomingData.equals("CONNECTED~")) {
    //  incomingData = "";
    //  println("CONNECTED");
    //  connectionToggle.setValue(1.0);
    //  isDeviceConnected = true;
    //}

    if (comPortList.isMousePressed()) {
      comPortList.clear();
      for (int i = 0; i < Serial.list().length; i++) {
        comPortList.addItem(Serial.list()[i], i);
      }
    }
    break;
  }
}

public void showButtons(boolean[] buttonDisplays) {
  for (int i = 0; i < buttonDisplays.length; i++) {
    if (buttonDisplays[i] == true) {
      image(buttonOnImages[i], buttonCoordinates[i][0], buttonCoordinates[i][1]);
    } else {
      image(buttonOffImages[i], buttonCoordinates[i][0], buttonCoordinates[i][1]);
    }
  }
}
public void serialEvent(Serial mgPort) {
  incomingData = mgPort.readString();
  println("SERIAL EVENT: " + incomingData);

  String dataType = incomingData.substring(0, 4); // Check if incoming data contains information from Buttons Presses, Bank changes, Trigger Info, and Display Info, LOAD data etc.
  int bank;
  switch (dataType) {
  case "CONN":
    println("CONNECTED");
    connectionToggle.setValue(1.0f);
    isDeviceConnected = true;
    incomingData = "";
    mgPort.write("L~"); // auto Load data
    break;
  case "LOAD":
    bank = PApplet.parseInt(incomingData.substring(incomingData.indexOf(',') + 1, incomingData.length() - 1));
    bankIndex = bank;
    parseData(incomingData);
    incomingData = "";
    break;
  case "BUTT":
    String buttonSubstring = incomingData.substring(incomingData.indexOf(',') + 1, incomingData.length() - 1);
    int button = buttonSubstring.charAt(0) - '0';
    boolean value = PApplet.parseBoolean(buttonSubstring.charAt(1) - '0');
    buttonDisplays[button] = value;
    incomingData = "";
    break;

  case "BANK":
    bank = PApplet.parseInt(incomingData.substring(incomingData.indexOf(',') + 1, incomingData.length() - 1));
    bankIndex = bank;
    updateGui(
      MasterVolume[bankIndex], 
      OscAWaveform[bankIndex], 
      OscAVolume[bankIndex], 
      OscBWaveform[bankIndex], 
      OscBVolume[bankIndex], 
      OscBDetune[bankIndex], 
      NoiseVolume[bankIndex], 
      LFOOnOff[bankIndex], 
      LFORate[bankIndex], 
      LFOAmount[bankIndex], 
      LFODest[bankIndex], 
      FilterOnOff[bankIndex], 
      FilterQ[bankIndex], 
      FilterCutoff[bankIndex], 
      TriggerDest[bankIndex][0], 
      TriggerDest[bankIndex][1], 
      TriggerDest[bankIndex][2], 
      TriggerDest[bankIndex][3], 
      AmpAttack[bankIndex], 
      AmpRelease[bankIndex]
      );
    //bankNumberbox.setValue(bank);
    incomingData = "";
    break;

  case "TRIG":
    int triggerValue = PApplet.parseInt(incomingData.substring(incomingData.indexOf(',') + 1, incomingData.length() - 1));
    triggerDelta = PApplet.parseInt(map(triggerValue, 1019, 524, 0, 30));
    break;
  }
}

// Event listener for all controller events
public void controlEvent(ControlEvent e) { 
  if (e.isFrom(comPortList)) { // if dropdown list has been clicked
    if (isDeviceConnected) { // clear and stop existing serial port if device is connected
      mgPort.clear();
      mgPort.stop();
    }
    portName = Serial.list()[PApplet.parseInt(e.getValue())]; // Connect to device
    mgPort = new Serial(this, portName, 115200);
    mgPort.bufferUntil('~');
    mgPort.write("C~");
  } else if (e.isFrom(connectionToggle)) {
    if (e.getValue() == 0.0f) {
      mgPort.write("D~");
      mgPort.clear();
      mgPort.stop();
      isDeviceConnected = false;
      //println(e.getValue());
    }
  } else if (e.isFrom(closeButton)) {
    if (isDeviceConnected) {
      mgPort.write("D~");
    }
    exit();
  } else if (e.isFrom(loadButton)) {
    if (isDeviceConnected) {
      mgPort.write("L~");
    }
  } else {
    if (isDeviceConnected) {
      String value = "";
      if (e.isFrom(triggerDestCheckBox)) { // if click is from checkbox, send array
        float[] checkBoxArray = e.getArrayValue();
        for (int i = 0; i < checkBoxArray.length; i++) {
          value = value + str(PApplet.parseInt(checkBoxArray[i])); // send string of 4 bits representing each check box
        }
      } else if (isDeviceConnected) {
        value = str(e.getValue());
      }
      mgPort.write('P' + e.getName() + "," + value + "~"); // P for parameter
      //println(e.getName() + "," + value + "~");
    }
  }
}

public void stop() {
  if (isDeviceConnected) {
    mgPort.write("DISCONNECT~");
  }
}

// Function to "Pixelize" an image for aesthetic effect, wink to Teenage Engineering's website
public void pixelateImage(int pixelWidth, PImage image) {
  int ratio = width/height;
  int pixelHeight = pixelWidth * ratio;
  for (int x = 0; x < width; x += pixelWidth) {
    for (int y = 0; y < height; y += pixelHeight) {
      fill(image.get(x, y));
      rect(x, y, pixelWidth, pixelHeight);
    }
  }
}

public void splashSequence(float time1, float time2, float time3) {
  image(splashScreen, 0, 0); // show splash screen for X amount of time
  if (frameCount < (30 * time1)) {
    pixelateImage(15, splashScreen); // pixelates splashscreen image (for fun)
  } else if (frameCount < (30 * time2)) {
    pixelateImage(5, splashScreen);
  }
}

// Function to Parse data dump from device
public void parseData(String loadData) {
  String[] dataPerBank = new String[numberOfBanks];

  for (int i = 0; i < numberOfBanks; i++) { // parse all incoming data into per-bank sections
    dataPerBank[i] = loadData.substring(loadData.indexOf("bank:" + str(i)), loadData.indexOf("bank:" + str(i + 1)));

    String[] splitData = split(dataPerBank[i], '\n'); // split up strings into individual variables

    // populate arrays with data, this needs to be refactored at some point
    MasterVolume[i] = PApplet.parseFloat(splitData[1].substring((splitData[1].indexOf(':') + 1), splitData[1].length()));

    OscAWaveform[i] = PApplet.parseInt(splitData[2].substring((splitData[2].indexOf(':') + 1), splitData[2].length()));
    OscAVolume[i] = PApplet.parseFloat(splitData[3].substring((splitData[3].indexOf(':') + 1), splitData[3].length()));

    OscBWaveform[i] = PApplet.parseInt(splitData[4].substring((splitData[4].indexOf(':') + 1), splitData[4].length()));
    OscBVolume[i] = PApplet.parseFloat(splitData[5].substring((splitData[5].indexOf(':') + 1), splitData[5].length()));
    OscBDetune[i] = PApplet.parseFloat(splitData[6].substring((splitData[6].indexOf(':') + 1), splitData[6].length()));

    NoiseVolume[i] = PApplet.parseFloat(splitData[7].substring((splitData[7].indexOf(':') + 1), splitData[7].length()));

    LFOOnOff[i] = PApplet.parseInt(splitData[8].substring((splitData[8].indexOf(':') + 1), splitData[8].length()));
    LFORate[i] = PApplet.parseFloat(splitData[9].substring((splitData[9].indexOf(':') + 1), splitData[9].length()));
    LFOAmount[i] = PApplet.parseFloat(splitData[10].substring((splitData[10].indexOf(':') + 1), splitData[10].length()));
    LFODest[i] = PApplet.parseInt(splitData[11].substring((splitData[11].indexOf(':') + 1), splitData[11].length()));

    FilterOnOff[i] = PApplet.parseInt(splitData[12].substring((splitData[12].indexOf(':') + 1), splitData[12].length()));
    FilterQ[i] = PApplet.parseFloat(splitData[13].substring((splitData[13].indexOf(':') + 1), splitData[13].length()));
    FilterCutoff[i] = PApplet.parseFloat(splitData[14].substring((splitData[14].indexOf(':') + 1), splitData[14].length()));

    TriggerDest[i][0] = PApplet.parseInt(splitData[15].substring((splitData[15].indexOf(':') + 1), splitData[15].length()));
    TriggerDest[i][1] = PApplet.parseInt(splitData[16].substring((splitData[16].indexOf(':') + 1), splitData[16].length()));
    TriggerDest[i][2] = PApplet.parseInt(splitData[17].substring((splitData[17].indexOf(':') + 1), splitData[17].length()));    
    TriggerDest[i][3] = PApplet.parseInt(splitData[18].substring((splitData[18].indexOf(':') + 1), splitData[18].length()));

    AmpAttack[i] = PApplet.parseInt(splitData[19].substring((splitData[19].indexOf(':') + 1), splitData[19].length()));
    AmpRelease[i] = PApplet.parseInt(splitData[20].substring((splitData[20].indexOf(':') + 1), splitData[20].length()));
  }
  //println(LFOOnOff);
}
public void setupGui() {

  PFont smallFont;
  smallFont = loadFont("Avenir-Light-10.vlw"); // Setup Font

  //////////////////////////////////////////////////////////////
  // GUI COMPONENTS FOR OSCILLATOR A

  closeButton = cp5.addButton("closeButton")
    .setImages(loadImage("close-button-off.png"), loadImage("close-button-off.png"), loadImage("close-button-on.png"))
    .setPosition(966, 3)
    ;



  oscAWaveformRadioButton = cp5.addRadioButton("oscAWaveform")
    .setPosition(33, 250)
    .setImages(loadImage("radio-button-off.png"), loadImage("radio-button-hover.png"), loadImage("radio-button-on.png"))
    .setSize(15, 15)
    .setItemsPerRow(1)
    .setSpacingColumn(20)
    .setSpacingRow(6)
    .addItem("SINE A", 0) // 0:Sine, 1:Sawtooth, 2:Square, 3:Triangle, 6:Reverse Saw
    .addItem("SAW A", 1)
    .addItem("REV SAW A", 6)
    .addItem("SQUARE A", 2)
    .addItem("TRIANGLE A", 3)
    .setArrayValue(defaultOscAWaveform)
    ;

  oscAVolumeKnob = cp5.addKnob("oscAVolume")
    .setPosition(132, 258)
    .setRange(0, 1.0f)
    .setColorBackground(darkYellow)
    .setColorForeground(0)
    .setColorActive(0)
    .setValue(0.5f)
    .setLabelVisible(false)
    .setRadius(35)
    .setDragDirection(Knob.VERTICAL)
    .setLabel("Volume")
    ;


  //////////////////////////////////////////////////////////////
  // GUI COMPONENTS FOR OSCILLATOR B

  oscBWaveformRadioButton = cp5.addRadioButton("oscBWaveform")
    .setPosition(33, 440)
    .setImages(loadImage("radio-button-off.png"), loadImage("radio-button-hover.png"), loadImage("radio-button-on.png"))
    .setItemsPerRow(1)
    .setSpacingColumn(20)
    .setSpacingRow(5)
    .addItem("SINE B", 0) // 0:Sine, 1:Sawtooth, 2:Square, 3:Triangle, 6:Reverse Saw
    .addItem("SAW B", 1)
    .addItem("REV SAW B", 6)
    .addItem("SQUARE B", 2)
    .addItem("TRIANGLE B", 3)
    .setArrayValue(defaultOscBWaveform)
    ;

  oscBVolumeKnob = cp5.addKnob("oscBVolume")
    .setPosition(132, 443)
    .setRange(0, 1.0f)
    .setValue(0.5f)
    .setColorBackground(darkYellow)
    .setColorForeground(0)
    .setColorActive(0)
    .setLabelVisible(false)
    .setRadius(35)
    .setDragDirection(Knob.VERTICAL)
    .setLabel("Volume")
    ;

  oscBDetuneKnob = cp5.addKnob("oscBDetune")
    .setPosition(232, 443)
    .setColorBackground(darkYellow)
    .setColorForeground(0)
    .setColorActive(0)
    .setRange(0, 2)
    .setValue(1)
    .setLabelVisible(false)
    .setRadius(35)
    .setDragDirection(Knob.VERTICAL)
    .setLabel("Detune")
    ;

  //////////////////////////////////////////////////////////////
  // GUI COMPONENTS FOR FILTER

  filterOnOffToggle = cp5.addToggle("filterOnOff")
    .setPosition(37, 651)
    .setImages(loadImage("toggle-off.png"), loadImage("toggle-on.png"))
    .setValue(0)
    .setSize(80, 80)
    ;

  filterCutoffKnob = cp5.addKnob("filterCutoff")
    .setPosition(132, 621)
    .setRange(0, 8000)
    .setColorBackground(darkYellow)
    .setColorForeground(0)
    .setColorActive(0)
    .setValue(5)
    .setLabelVisible(false)
    .setRadius(35)
    .setDragDirection(Knob.VERTICAL)
    .setLabel("Cutoff")
    ;

  filterQKnob = cp5.addKnob("filterQ")
    .setPosition(232, 621)
    .setRange(0.7f, 5)
    .setColorBackground(darkYellow)
    .setColorForeground(0)
    .setColorActive(0)
    .setLabelVisible(false)
    .setValue(0.707f)
    .setRadius(35)
    .setDragDirection(Knob.VERTICAL)
    .setLabel("Resonance")
    ;

  //////////////////////////////////////////////////////////////
  // GUI COMPONENTS FOR LFO

  lfoOnOffToggle = cp5.addToggle("lfoOnOff")
    .setPosition(367, 651)
    .setImages(loadImage("toggle-off.png"), loadImage("toggle-on.png"))
    .setValue(0)
    .setSize(40, 40)
    ;

  lfoRateKnob = cp5.addKnob("lfoRate")
    .setPosition(458, 621)
    .setRange(0, 10)
    .setColorBackground(darkYellow)
    .setColorForeground(0)
    .setColorActive(0)
    .setLabelVisible(false)
    .setValue(0)
    .setRadius(35)
    .setDragDirection(Knob.VERTICAL)
    .setLabel("LFO Rate")
    ;

  lfoAmountKnob = cp5.addKnob("lfoAmount")
    .setPosition(564, 621)
    .setColorBackground(darkYellow)
    .setColorForeground(0)
    .setColorActive(0)
    .setLabelVisible(false)
    .setRange(0, 1.0f)
    .setValue(0.5f)
    .setRadius(35)
    .setDragDirection(Knob.VERTICAL)
    .setLabel("LFO Amount")
    ;



  //////////////////////////////////////////////////////////////
  // GUI COMPONENTS FOR AMP ENVELOPE

  ampAttackKnob = cp5.addKnob("ampAttack")
    .setPosition(697, 621)
    .setRange(0, 1000)
    .setColorBackground(darkYellow)
    .setColorForeground(0)
    .setColorActive(0)
    .setLabelVisible(false)
    .setValue(0)
    .setRadius(35)
    .setDragDirection(Knob.VERTICAL)
    .setLabel("Attack")
    ;

  ampReleaseKnob = cp5.addKnob("ampRelease")
    .setPosition(795, 621)
    .setRange(0, 1000)
    .setColorBackground(darkYellow)
    .setColorForeground(0)
    .setColorActive(0)
    .setValue(0)
    .setLabelVisible(false)
    .setRadius(35)
    .setDragDirection(Knob.VERTICAL)
    .setLabel("Release")
    ;

  masterVolumeKnob = cp5.addKnob("masterVolume")
    .setPosition(895, 621)
    .setRange(0, 1)
    .setColorBackground(darkYellow)
    .setColorForeground(0)
    .setColorActive(0)
    .setValue(0.5f)
    .setLabelVisible(false)
    .setRadius(35)
    .setDragDirection(Knob.VERTICAL)
    .setLabel("Master Volume")
    ;


  ///////////////////////////////////////////////////////////////
  // GUI COMPONENTS FOR TRIGGER


  triggerDestCheckBox = cp5.addCheckBox("triggerDest")
    .setPosition(363, 465)
    .setImages(loadImage("radio-button-off.png"), loadImage("radio-button-hover.png"), loadImage("radio-button-on.png"))
    .setSize(15, 15)
    .setItemsPerRow(1)
    .setSpacingColumn(20)
    .setSpacingRow(6)
    .addItem("OSC B DETUNE", 0) // multiple destinations can be selected at once
    .addItem("FILTER", 1)
    .addItem("LFO RATE", 2)
    .addItem("LFO AMOUNT", 3)
    ;

  //////////////////////////////////////////////////////////////
  // GUI COMPONENTS FOR LOAD SAVE

  //saveButton = cp5.addButton("saveButton")
  //  .setPosition(859, 52)
  //  .setSize(80, 60)
  //  .setImages(loadImage("save-button-off.png"), loadImage("save-button-on.png"), loadImage("save-button-off.png"))
  //  .setLabel("SAVE CHANGES")
  //  .setLabelVisible(false)
  //  ;

  //loadButton = cp5.addButton("loadButton")
  //  .setPosition(723, 52)
  //  .setSize(80, 60)
  //  .setImages(loadImage("load-button-off.png"), loadImage("load-button-on.png"), loadImage("load-button-off.png"))
  //  .setLabel("SAVE CHANGES")
  //  .setLabelVisible(false)
  //  ;

  // Graphical Components for Device
  displayCheckBox = cp5.addCheckBox("displayCheckBox")
    .setPosition(446, 245)
    .setSize(13, 13)
    .setItemsPerRow(8)
    .setSpacingColumn(3)
    .setSpacingRow(3)
    .setColorBackground(color(125, 125, 125))
    .setColorActive(color(255, 0, 0))
    .setColorForeground(color(255, 127, 127))
    ;
  for (int i = 0; i < 64; i++) {
    displayCheckBox.addItem(str(i), i);
  }
  displayCheckBox.hideLabels();


  // GUI Components for COM PORT

  comPortList = cp5.addScrollableList("comPortList")
    .setPosition(16, 69)
    .setItemHeight(20)
    .setFont(smallFont)
    .setImages(loadImage("radio-button-off.png"), loadImage("radio-button-hover.png"), loadImage("radio-button-on.png"))
    .setBarHeight(25)
    .setHeight(17)
    .setSize(225, 200)
    .setLabel("SELECT COM PORT")
    .setColorBackground(darkYellow)
    .setColorForeground(lightYellow)
    .setColorLabel(black)
    .setColorValue(black)
    ;

  connectionToggle = cp5.addToggle("connectionToggle")
    .setPosition(257, 127)
    .setSize(50, 50)
    .setImages(loadImage("connection-toggle-off.png"), loadImage("connection-toggle-hover.png"), loadImage("connection-toggle-on.png"))
    .setValue(0)
    ;
}
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
  static public void main(String[] passedArgs) {
    String[] appletArgs = new String[] { "moon_germs_app" };
    if (passedArgs != null) {
      PApplet.main(concat(appletArgs, passedArgs));
    } else {
      PApplet.main(appletArgs);
    }
  }
}

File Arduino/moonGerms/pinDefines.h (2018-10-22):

#define BUTTON_1 2
#define BUTTON_2 3
#define BUTTON_3 4
#define BUTTON_4 5

#define LOW_BATTERY A7
#define TRIGGER A2
#define IR_SENSOR A6

#define SDCARD_CS_PIN    10
#define SDCARD_MOSI_PIN  7
#define SDCARD_SCK_PIN   14

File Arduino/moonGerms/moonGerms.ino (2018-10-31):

// Moon Germs Handheld Synthesizer
// V0.1 Arduino Code, October 2018
// By Kenneth Marut (www.kennethmarut.com)
//
// Hardware and software files can be found at: https://github.com/friedpies/moon-germs
// Project Details: https://hackaday.io/project/161208-moon-germs
// License: MIT

#include <Audio.h>
#include <Wire.h>
#include <SPI.h>
#include <SD.h>
#include <SerialFlash.h>
#include <Bounce.h>
#include <Adafruit_GFX.h>
#include "Adafruit_LEDBackpack.h"

#include "pinDefines.h"
#include "audioConnections.h"
#include "bitMaps.h"
#include "aLookup.h"
#include "globalVariables.h"

void setup() {
  delay(2000); // safety
  Serial.begin(115200); // Initialize Serial port for communication with desktop app (eventually will also include midi?)
  matrix.begin(0x70); // Initialize display and set to blank
  matrix.clear();
  matrix.setRotation(1);
  matrix.drawBitmap(0, 0, emptyBMP, 8, 8, LED_RED);
  matrix.writeDisplay();

  updateCurrentAnimation(bank); // set current animation to Saw
  pinMode(BUTTON_1, INPUT_PULLUP);
  pinMode(BUTTON_2, INPUT_PULLUP);
  pinMode(BUTTON_3, INPUT_PULLUP);
  pinMode(BUTTON_4, INPUT_PULLUP);

  SPI.setMOSI(SDCARD_MOSI_PIN); // set up SD. Will eventually use to store bank data
  SPI.setSCK(SDCARD_SCK_PIN);
  if (!(SD.begin(SDCARD_CS_PIN))) {
    while (1) {
      Serial.println("Unable to access the SD card");
      delay(500);
    }
  }

  //Audio setup (see audioSetupFunctions tab)
  setupAudio();
  bootupAnimation();
}

void loop() {
  button1.update();
  button2.update();
  button3.update();
  button4.update();

  // See "inputChecks" tab for function details
  readButton1();   // Detect if Play button is pressed or if "pressPlay" is received from App, and play note
  readButton2();   // Detect waveform button for press and switch waveform type
  readButton3();  // Increase octave
  readButton4(); // Decrease Octave
  readTrigger(); // Read input from trigger
  readIRSensor(); // Adjust pitch

  if (playAnimation) {
    if ((millis() - lastMillis) > frameRate) {
      if (currentFrame == animationLength) {
        currentFrame = 0;
      }
      matrix.clear();
      matrix.drawBitmap(0, 0, currentAnimation[currentFrame], 8, 8, displayColor);
      matrix.writeDisplay();
      currentFrame++;
      lastMillis = millis();
    }
  }
}

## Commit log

2018-09-25 Added button functionality
2018-10-04 Fixed glitch in display
    [inputChecks.ino, moonGerms.ino, pinDefines.h]
2018-10-05 Fixed glitch, added detune functionality
    [animationFunctions.ino, inputChecks.ino, moonGerms.ino]
2018-10-05 Adding Readme and documentation
    [moon-germs.brd, moon-germs.sch]
2018-10-05 updating readme
    [moon-germs.sch]
2018-10-05 added 3D print files
    [MOON_GERMS_DISPLAY_SHIELD.dxf, MOON_GERMS_ENCLOSURE_BOTTOM.stl, MOON_GERMS_ENCLOSURE_TOP.stl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]
2018-10-07 changed frequency mapping, added gif of spring
2018-10-17 Added buttons and knobs etc. building out GUI
2018-10-20 added more assets, variable update functions
    [moon-germs-japanese.dxf, moon-germs.dxf]
2018-10-20 fixed bug in spacebar
    [functions.pde, globalVariables.h, guiSetup.pde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]
2018-10-20 tired of coding, working on UI for app
2018-10-21 redesigned interface, tired from coding
    [guiSetup.pde]
2018-10-22 Updating readme, adding assets etc.
    [moon-germs-japanese.dxf, moon-germs.dxf]

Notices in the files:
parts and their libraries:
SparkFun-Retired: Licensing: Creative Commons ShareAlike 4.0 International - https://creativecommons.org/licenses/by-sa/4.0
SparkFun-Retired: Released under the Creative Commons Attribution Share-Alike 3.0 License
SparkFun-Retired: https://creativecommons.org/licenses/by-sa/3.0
